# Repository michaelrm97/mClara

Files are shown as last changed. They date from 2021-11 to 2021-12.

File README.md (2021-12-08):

# Clara Mini

## Background

The other Project C.L.A.R.A (Christmas Light Array Running on Azure) was conceived in 2020 as an LED Christmas light display controllable from the web. See [https://github.com/michaelrm97/clara](https://github.com/michaelrm97/clara) for information about the previous project.

## Components

There are three components of this:

- PCB with an LED light array in the shape of a Christmas card
- Laser cut plywood covers glued to the back and front of the PCB. The front contains a Christmas tree graphic and the back contains a festive greeting with a QR code linking to a personal message
- Web app hosting the card message. See [README](./software/README.md)

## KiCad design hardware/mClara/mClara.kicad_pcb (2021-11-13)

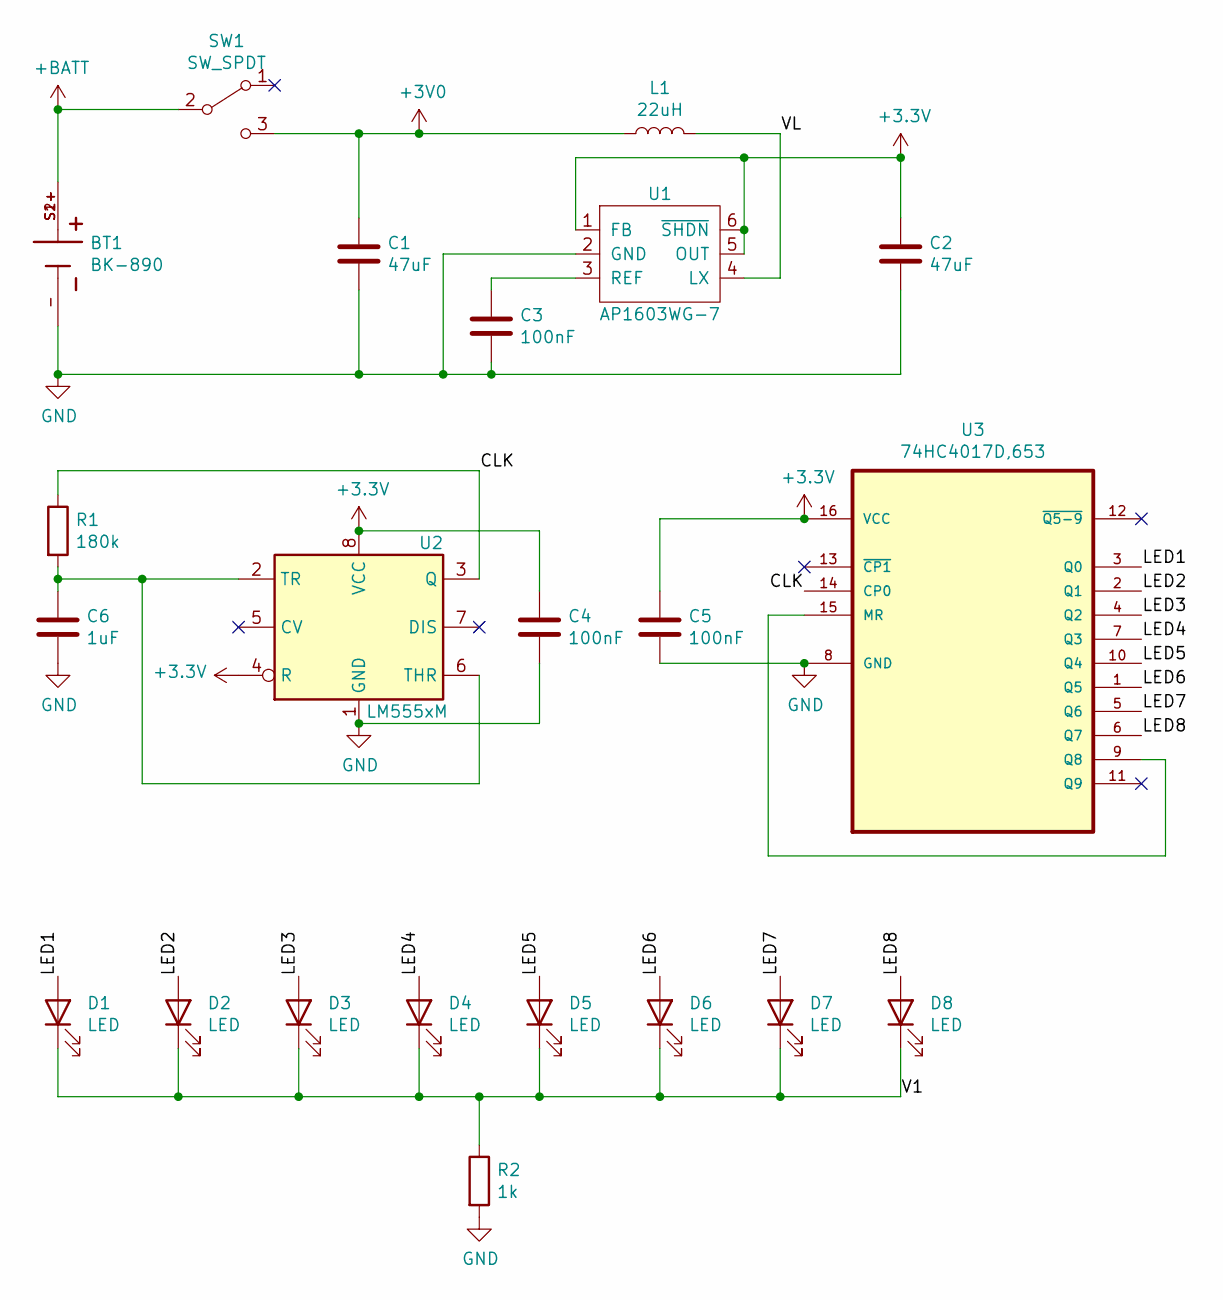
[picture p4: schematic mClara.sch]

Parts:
BT1: BK-890; BAT_BK-890; PARTREV E
C1, C2: 47uF; C_1206_3216Metric_Pad1.33x1.80mm_HandSolder; MPN CL31A476MQHNNWE
C3, C4, C5: 100nF; C_0603_1608Metric_Pad1.08x0.95mm_HandSolder; MPN CL10B104KB8NNWC
C6: 1uF; C_0603_1608Metric_Pad1.08x0.95mm_HandSolder; MPN CL10A105KO8NNNC
D1, D2, D3, D4, D5, D6, D7, D8: LED; LED_0603_1608Metric_Pad1.05x0.95mm_HandSolder; MPN IN-S63AT5UW
L1: 22uH; L_1812_4532Metric_Pad1.30x3.40mm_HandSolder; MPN LQH43PN220M26L
R1: 180k; R_0603_1608Metric_Pad0.98x0.95mm_HandSolder; MPN RMCF0603FT180K
R2: 1k; R_0603_1608Metric_Pad0.98x0.95mm_HandSolder; MPN RMCF0603JJ1K00
SW1: SW_SPDT; SW_PCM12SMTR; MPN PCM12SMTR
U1: AP1603WG-7; SOT-23-6_Handsoldering; MPN AP1603WG-7
U2: LM555xM; SOIC-8_3.9x4.9mm_P1.27mm; MPN TLC555IDR
U3: 74HC4017D,653; SO-16_3.9x9.9mm_P1.27mm; MPN 74HC4017D,653

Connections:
+3V0: C1.1, L1.1, SW1.3 (C)
+3V3: C2.1, C4.1, C5.1, U1.1 (FB), U1.5 (OUT), U1.6 (~SHDN), U2.4 (R), U2.8 (VCC), U3.16 (VCC)
+BATT: BT1.S1+, BT1.S2+, SW1.2 (B)
/CLK: R1.1, U2.3 (Q), U3.14 (CP0)
/LED1: D1.2 (A), U3.3 (Q0)
/LED2: D2.2 (A), U3.2 (Q1)
/LED3: D3.2 (A), U3.4 (Q2)
/LED4: D4.2 (A), U3.7 (Q3)
/LED5: D5.2 (A), U3.10 (Q4)
/LED6: D6.2 (A), U3.1 (Q5)
/LED7: D7.2 (A), U3.5 (Q6)
/LED8: D8.2 (A), U3.6 (Q7)
/V1: D1.1 (K), D2.1 (K), D3.1 (K), D4.1 (K), D5.1 (K), D6.1 (K), D7.1 (K), D8.1 (K), R2.1
/VL: L1.2, U1.4 (LX)
GND: BT1.-, C1.2, C2.2, C3.2, C4.2, C5.2, C6.2, R2.2, U1.2 (GND), U2.1 (GND), U3.8 (GND)
unnamed: C3.1, U1.3 (REF)
unnamed: C6.1, R1.2, U2.2 (TR), U2.6 (THR)
unnamed: U3.9 (Q8), U3.15 (MR)

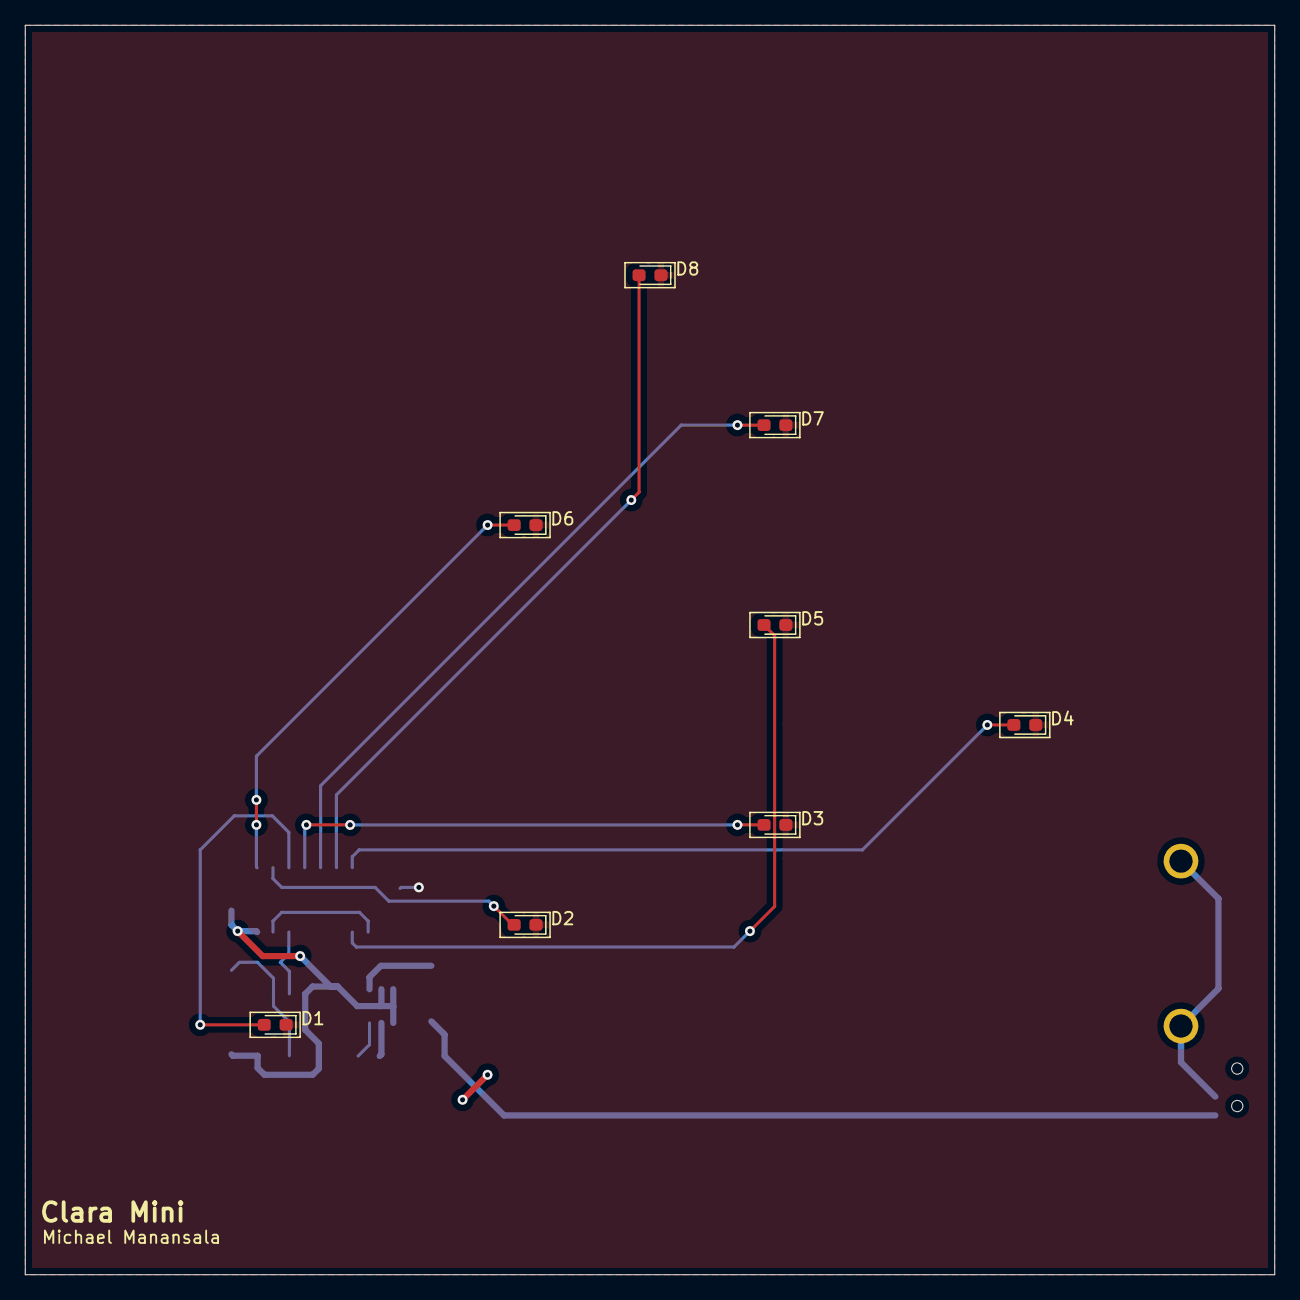
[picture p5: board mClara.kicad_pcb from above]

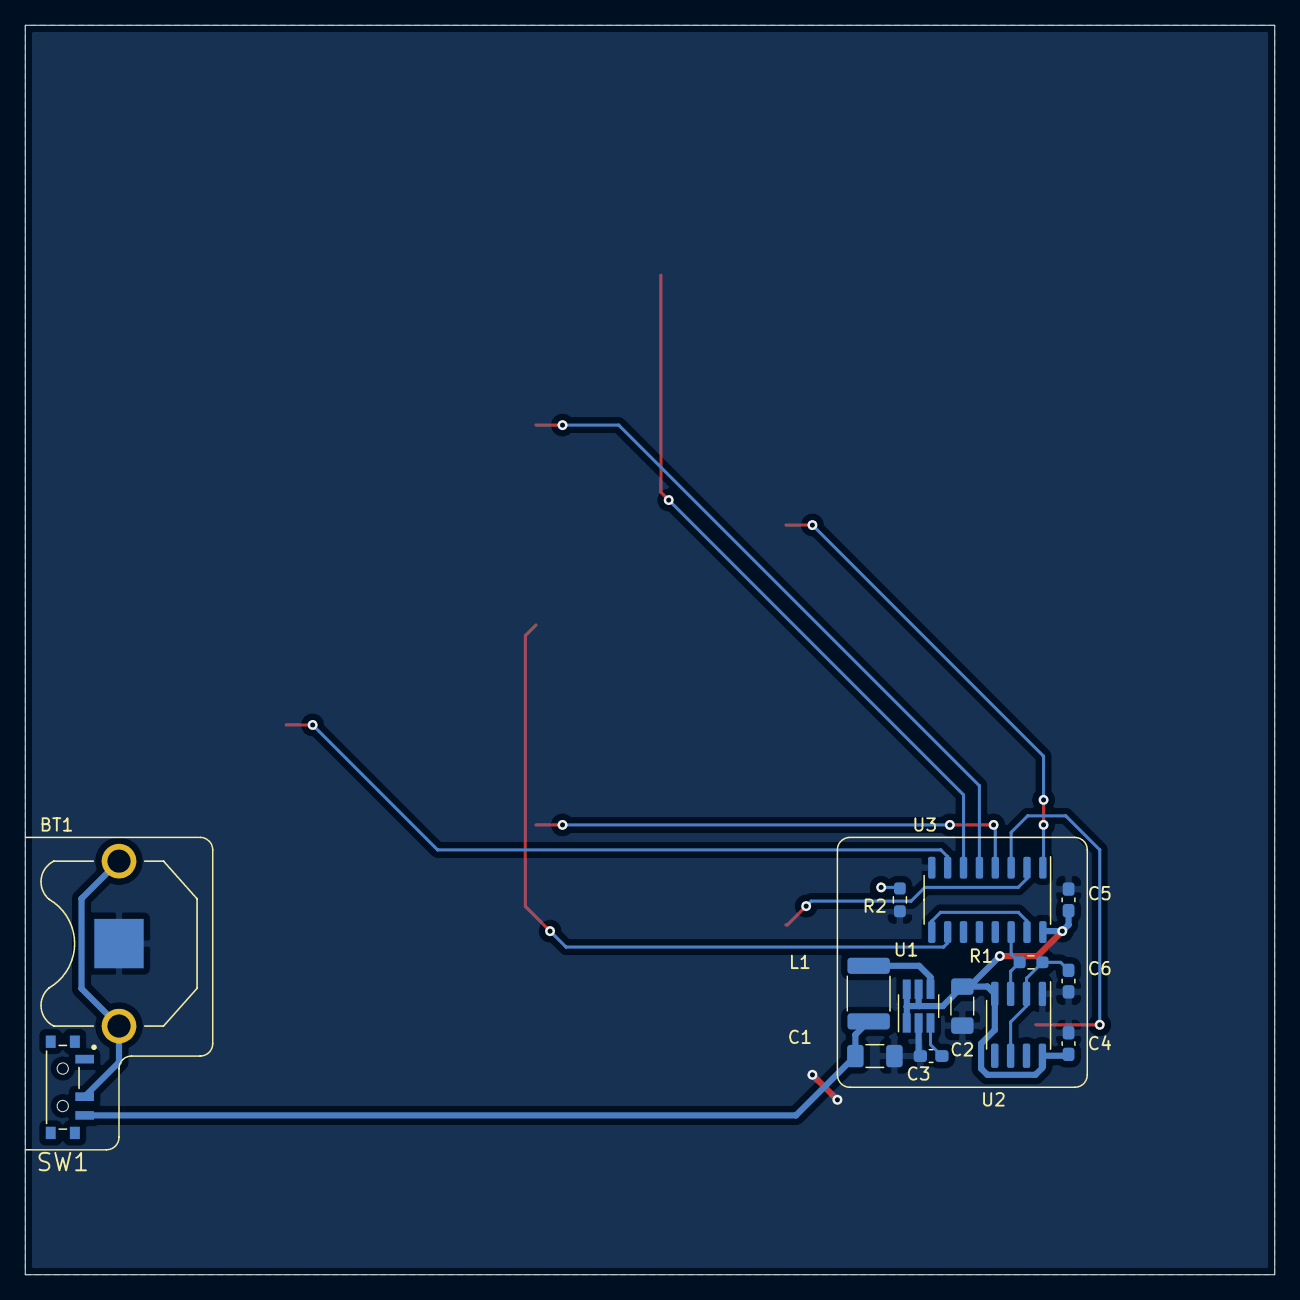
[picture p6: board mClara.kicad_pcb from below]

Board: 2 copper layers, 100.0 x 100.0 mm, 22 parts (14 on the bottom side), 18 nets.

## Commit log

2021-11-13 Checking in hardware and housing
    [mClara.kicad_pcb, mClara.sch]
2021-11-16 Implemented basic store and PowerShell commands
2021-11-21 Checked in PowerShell module
2021-11-22 Implemented rest of PowerShell cmdlets
2021-12-13 Added GetNames switch to Get-Logs
